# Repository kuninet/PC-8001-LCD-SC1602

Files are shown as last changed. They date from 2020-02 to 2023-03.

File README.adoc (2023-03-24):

= LCD SC1603 BOARD for PC-8001 

== 概要
* 16桁x2行のLCDモジュール SC1602(HD44780コンパチブル)をPC-8001拡張バスへ接続するボードです。

= ☆REV1 基板にはバグがあります☆
== アドレスデコーダーの配線に間違いがあります。ハード的に 74HC138の端子にジャンパ線を結ぶか、ソフトのパラメーターを工夫してください。m(_ _)m

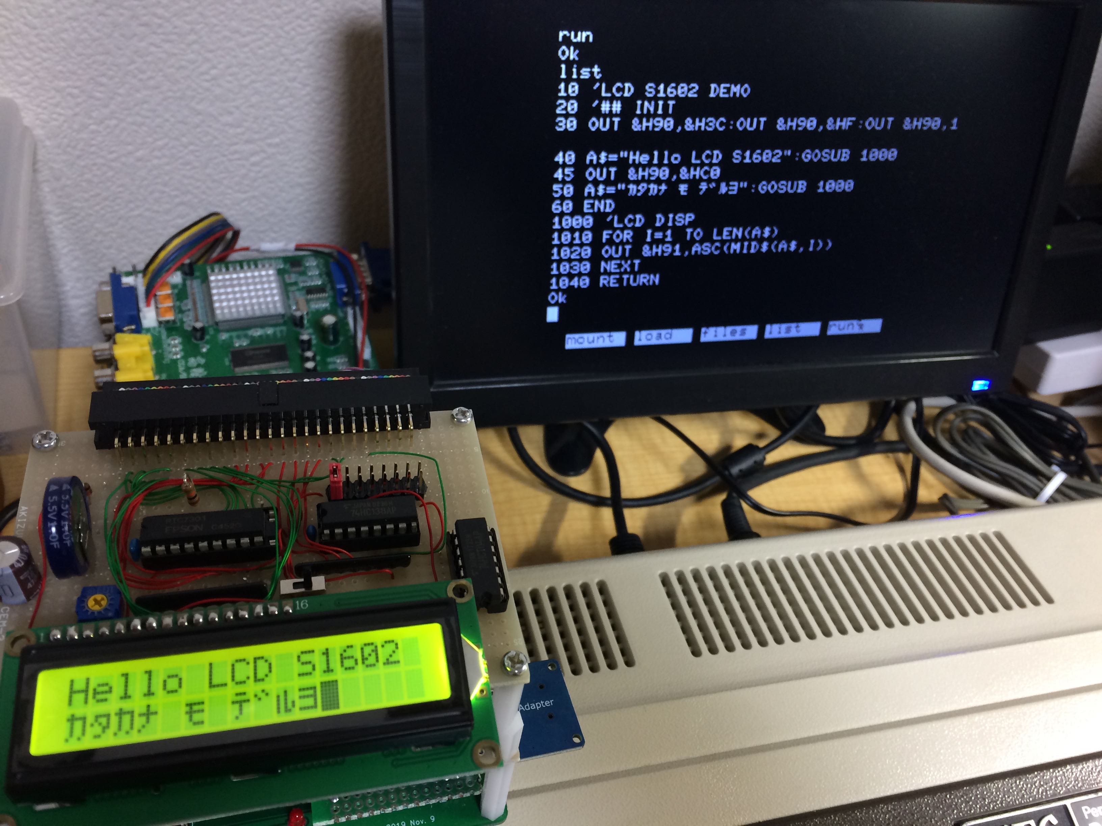
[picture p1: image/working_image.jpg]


== 説明
* PC-8001拡張バス(背面50ピン)にSC1602(HD44780コンパチブル)を接続するボードです。
* 74HC138でI/Oアドレスデコードします。$80〜や$90〜に設定がおすすめ。

== I/Oアドレス($90〜の場合)
* I/Oアドレスを$90〜とした場合、以下のようなアドレスとなります。

|===
|I/Oアドレス|RD/WR|説明

|$90
|WR
|各種設定

|$91
|WR
|CG RAM、DDRAMへデータ書き込み

|$92
|RD
|Busyフラグ、CG RAM、DDRAMアドレス読み出し

|$93
|RD
|CG RAM、DDRAMからデータ読み出し

|===

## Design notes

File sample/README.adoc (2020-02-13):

= LCD SC1602ボード用 sample

* PC-8001上で動作するLCD SC1602ボード用 sampleプログラムです。

|===
|ファイル名|内容

|LCDTST.CMT
|LCDへ文字列を出力するN-BASICサンプル(CMT形式)

|LCDTST.txt
|LCDへ文字列を出力するN-BASICサンプル(テキスト形式)

|LCDTST.wav
|LCDへ文字列を出力するN-BASICサンプル(CMT音声形式)

|LCDTST.CMT
|LCDへ文字列を出力するN-BASICサンプル2。カタカナ入り(CMT形式)

|LCD-S.CMT
|LCDへ文字列を出力/入力するTL/1-PCサンプル。(CMT形式)

|LCD-S.txt
|LCDへ文字列を出力/入力するTL/1-PCサンプル。(テキスト形式)

|===

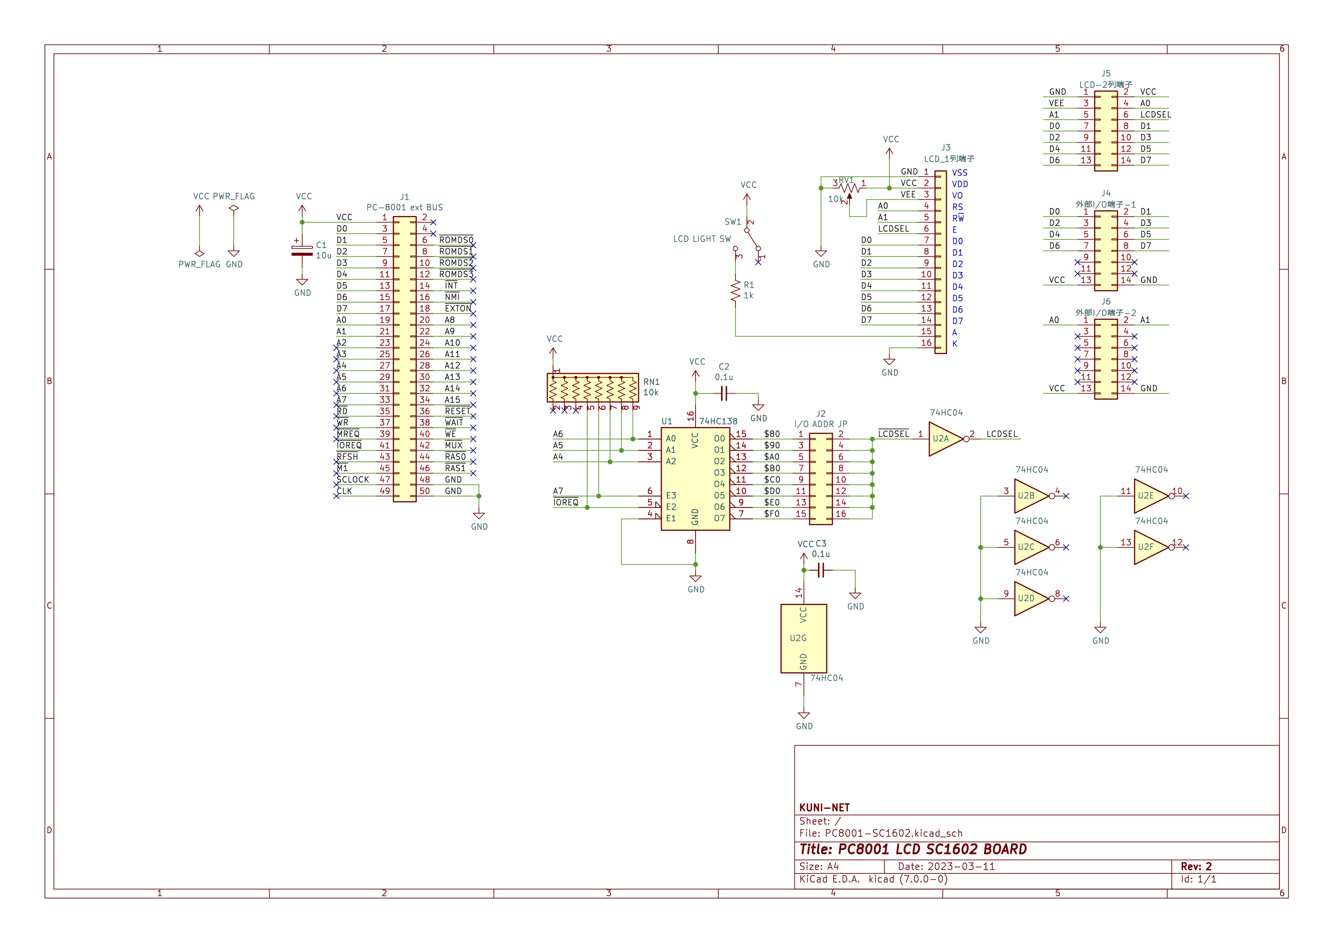
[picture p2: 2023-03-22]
image/PC8001-SC1602.jpg

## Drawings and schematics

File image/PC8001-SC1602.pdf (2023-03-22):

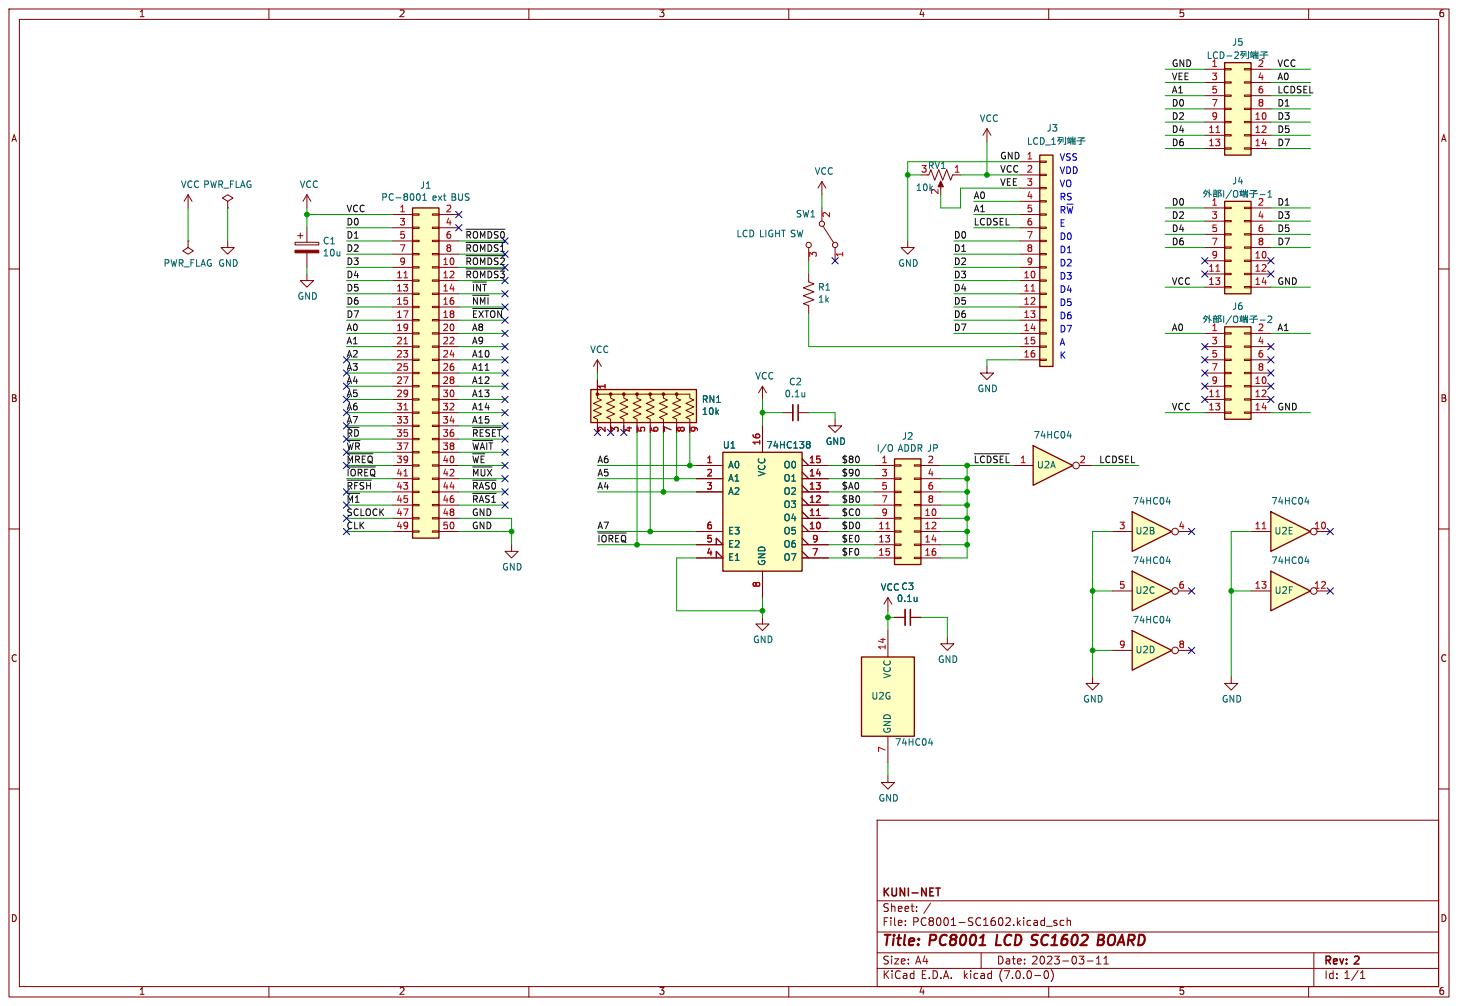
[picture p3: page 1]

þÿLCD-2Rzï[P GND GND

File: PC8001-SC1602.kicad_sch Sheet: / KUNI-NET

Id: 1/1 Title: PC8001 LCD SC1602 BOARD

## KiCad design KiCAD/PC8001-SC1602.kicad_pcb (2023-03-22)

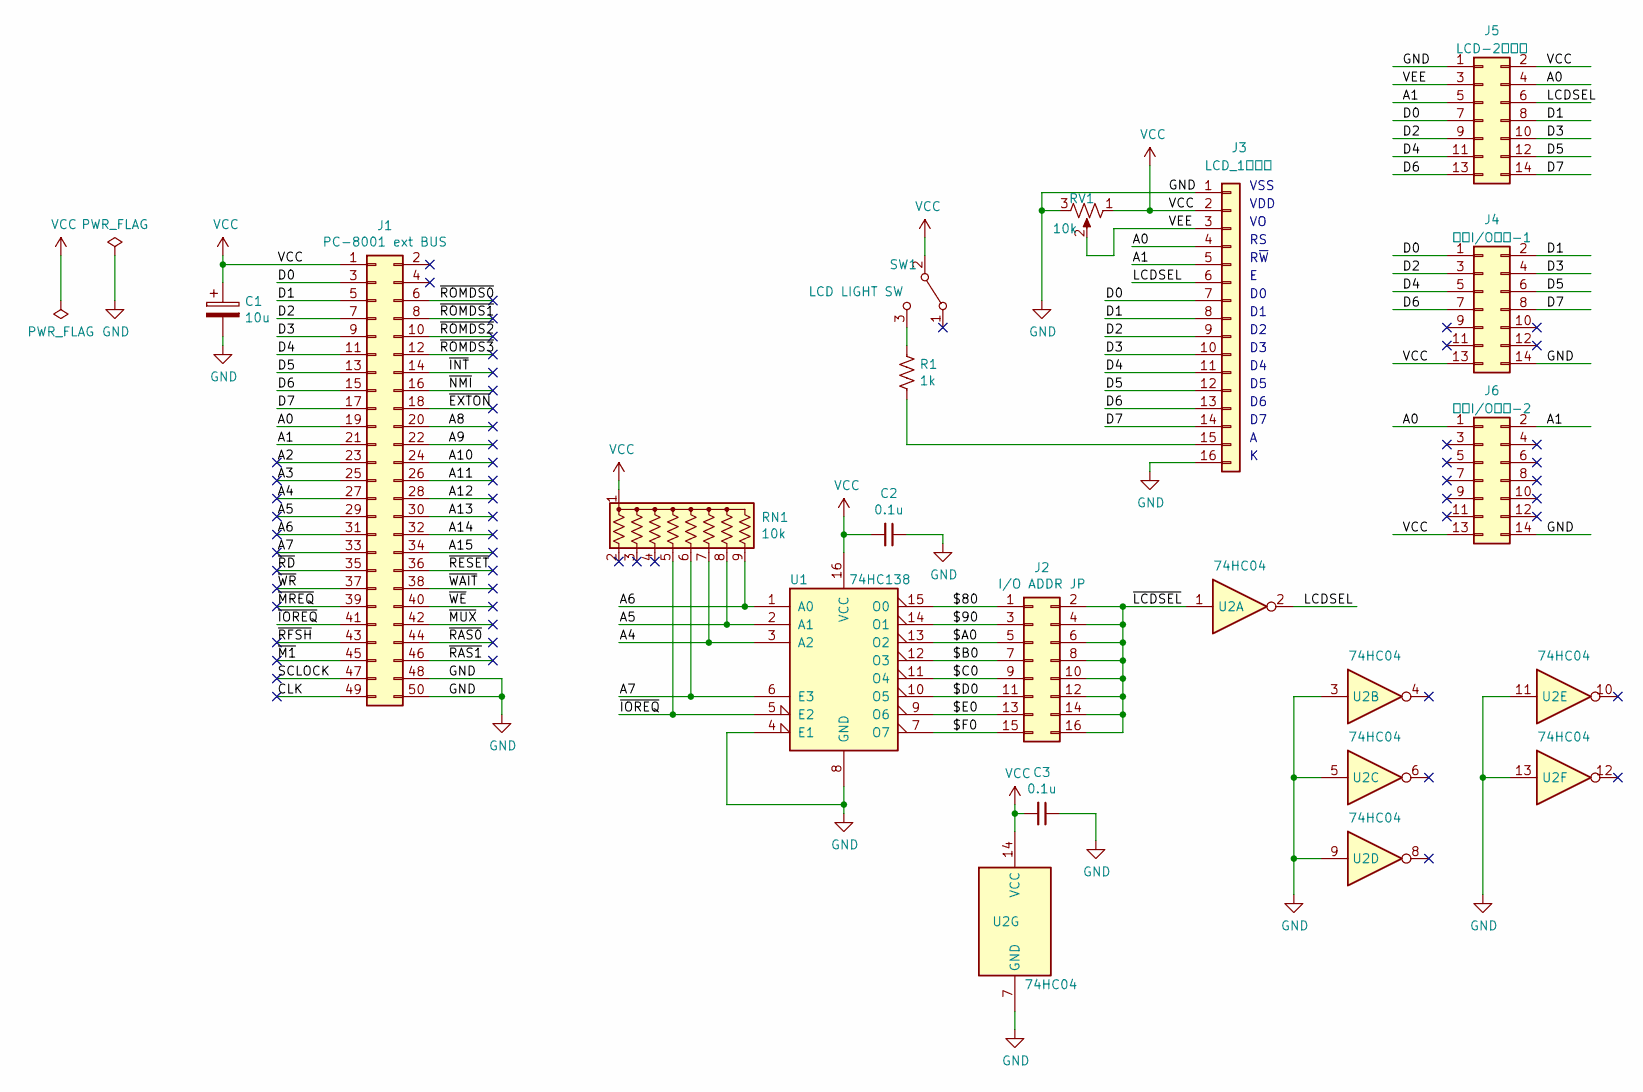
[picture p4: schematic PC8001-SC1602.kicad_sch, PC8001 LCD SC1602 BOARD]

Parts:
C1: 10u; CP_Radial_D5.0mm_P2.50mm
C2, C3: 0.1u; C_Disc_D3.0mm_W1.6mm_P2.50mm
J1: PC-8001 ext BUS; PinHeader_2x25_P2.54mm_Horizontal
J2: I/O ADDR JP; PinHeader_2x08_P2.54mm_Vertical
J3: LCD_1列端子; PinHeader_1x16_P2.54mm_Vertical
J4: 外部I/O端子-1; PinHeader_2x07_P2.54mm_Vertical
J5: LCD-2列端子; PinHeader_2x07_P2.54mm_Vertical
J6: 外部I/O端子-2; PinHeader_2x07_P2.54mm_Vertical
R1: 1k; R_Axial_DIN0207_L6.3mm_D2.5mm_P10.16mm_Horizontal
RN1: 10k; R_Array_SIP9
RV1: 10k; Potentiometer_Vishay_T73YP_Vertical
SW1: LCD LIGHT SW; PinHeader_1x03_P2.54mm_Vertical
U1: 74HC138; DIP-16_W7.62mm_Socket
U2: 74HC04; DIP-14_W7.62mm_Socket

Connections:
/$80: J2.1, U1.15 (O0)
/$90: J2.3, U1.14 (O1)
/$A0: J2.5, U1.13 (O2)
/$B0: J2.7, U1.12 (O3)
/$C0: J2.9, U1.11 (O4)
/$D0: J2.11, U1.10 (O5)
/$E0: J2.13, U1.9 (O6)
/A0: J1.19, J3.4, J5.4, J6.1
/A1: J1.21, J3.5, J5.5, J6.2
/A2: J1.23
/A3: J1.25
/A4: J1.27, RN1.7 (R6), U1.3 (A2)
/A5: J1.29, RN1.8 (R7), U1.2 (A1)
/A6: J1.31, RN1.9 (R8), U1.1 (A0)
/A7: J1.33, RN1.6 (R5), U1.6 (E3)
/A8: J1.20
/A9: J1.22
/A10: J1.24
/A11: J1.26
/A12: J1.28
/A13: J1.30
/A14: J1.32
/A15: J1.34
/CLK: J1.49
/D0: J1.3, J3.7, J4.1, J5.7
/D1: J1.5, J3.8, J4.2, J5.8
/D2: J1.7, J3.9, J4.3, J5.9
/D3: J1.9, J3.10, J4.4, J5.10
/D4: J1.11, J3.11, J4.5, J5.11
/D5: J1.13, J3.12, J4.6, J5.12
/D6: J1.15, J3.13, J4.7, J5.13
/D7: J1.17, J3.14, J4.8, J5.14
/LCDSEL: J3.6, J5.6, U2.2
/SCLOCK: J1.47
/VEE: J3.3, J5.3, RV1.2
/~EXTON: J1.18
/~INT: J1.14
/~IOREQ: J1.41, RN1.5 (R4), U1.5 (E2)
/~LCDSEL: J2.2, J2.4, J2.6, J2.8, J2.10, J2.12, J2.14, J2.16, U2.1
/~M1: J1.45
/~MREQ: J1.39
/~MUX: J1.42
/~NMI: J1.16
/~RAS0: J1.44
/~RAS1: J1.46
/~RD: J1.35
/~RESET: J1.36
/~RFSH: J1.43
/~ROMDS0: J1.6
/~ROMDS1: J1.8
/~ROMDS2: J1.10
/~ROMDS3: J1.12
/~WAIT: J1.38
/~WE: J1.40
/~WR: J1.37
GND: C1.2, C2.1, C3.1, J1.48, J1.50, J3.1, J3.16, J4.14, J5.1, J6.14, RV1.3, U1.4 (E1), U1.8 (GND), U2.3, U2.5, U2.7 (GND), U2.9, U2.11, U2.13
unnamed: J3.15, R1.2
unnamed: R1.1, SW1.3 (C)

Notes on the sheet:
VSS
VDD
R~{W}

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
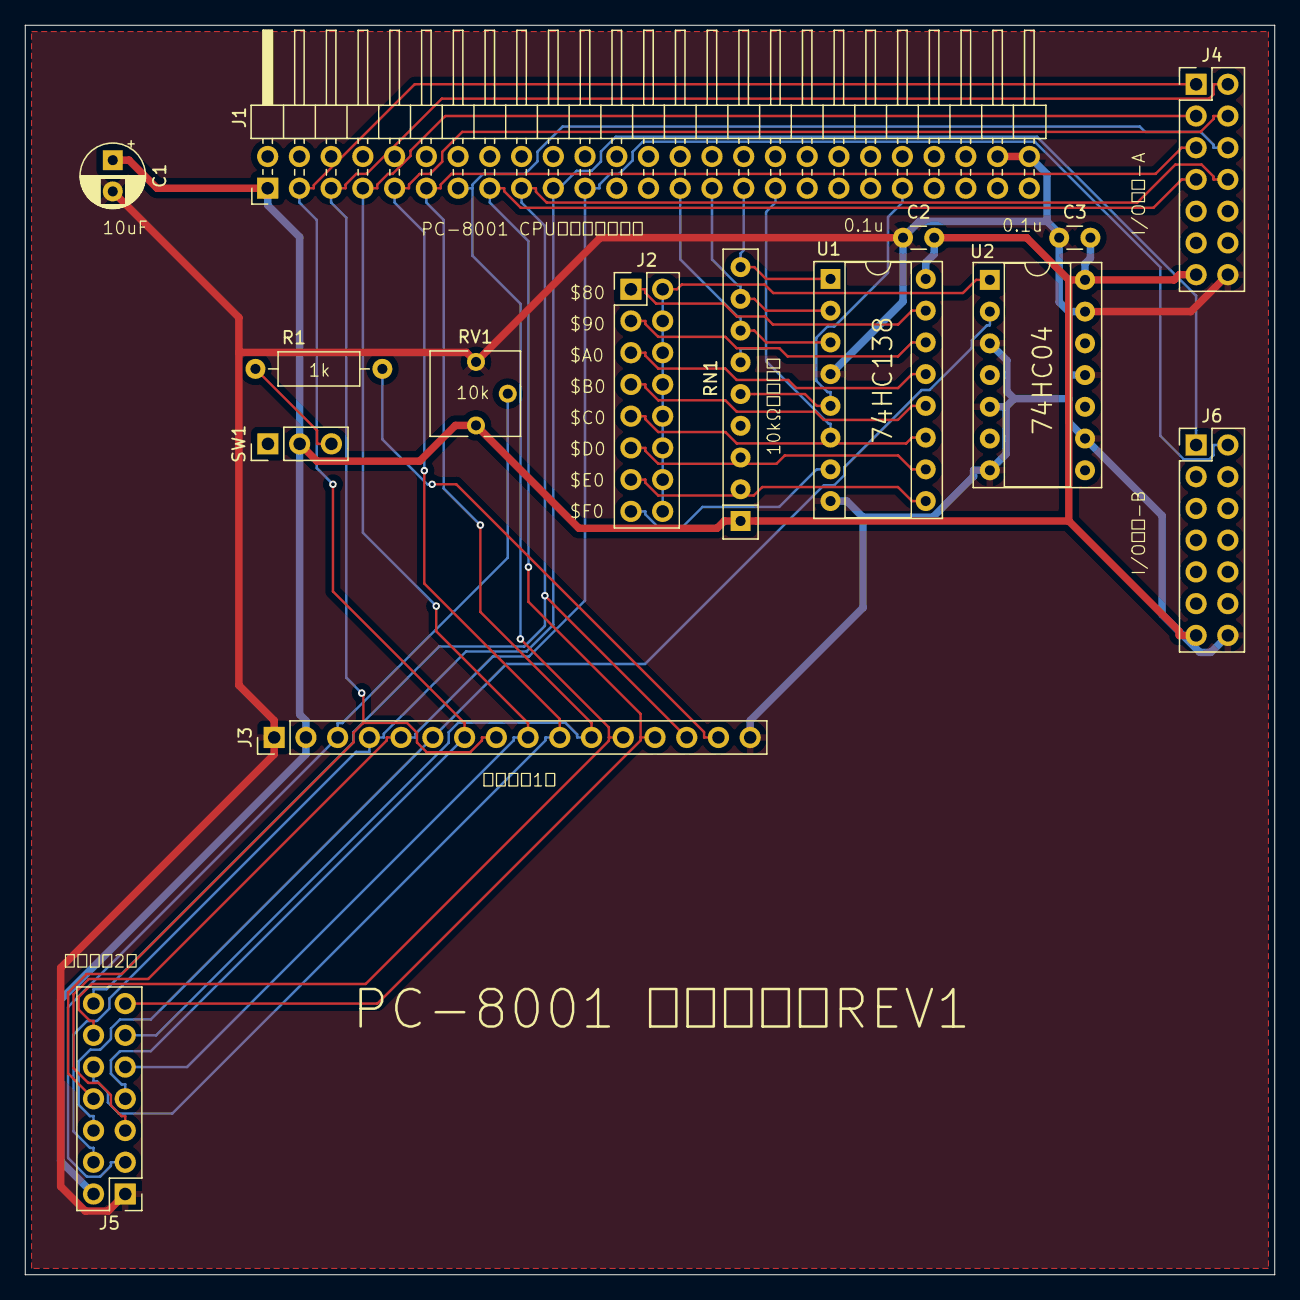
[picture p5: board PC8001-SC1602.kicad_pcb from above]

Board: 2 copper layers, 100.0 x 100.0 mm, 15 parts (0 on the bottom side), 29 nets.

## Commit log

2020-02-11 init commit
    [PC8001-SC1602.kicad_pcb, PC8001-SC1602.sch]
2020-02-11 README等整備
2020-02-11 回路図 微修正
    [PC8001-SC1602.sch]
2020-02-11 稼働イメージ画像添付
2020-02-11 readmeへ画像添付
2020-02-12 サンプルアプリ改良
2020-02-13 TL/1によるサンプル追加
2023-03-22 プリント基板データ作成 REV1
    [PC8001-SC1602.GBL, PC8001-SC1602.GBO, PC8001-SC1602.GBP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]
